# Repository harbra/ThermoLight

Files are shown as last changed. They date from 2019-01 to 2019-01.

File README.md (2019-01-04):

# ThermoLight - The IoT Thermometer & Display

## Project description
ThermoLight is a thermometer look-alike display that can show up to four values using NeoPixels & the ESP8266.

A more detailed description can be found on [hackster.io](https://www.hackster.io/har-bra/thermolight-the-iot-thermometer-display-c543e6).

## Repository contents
* C++ code that is running on the ESP8266, based on the Arduino core (in /code/esp8266)
* HTML/CSS/JS for webinterface, based on vue.js and Bulma (in /code/web)
* Schematic and PCB for the underlying electronics, created in KiCAD (in /pcb)
* Enclosure design, created in Fusion 360 (in /cad)

## Licenses
* All code is licensed with the [MIT license](https://opensource.org/licenses/MIT)
* Schematic, PCB and enclosure design are licensed with [CC-BY-SA-4.0](https://creativecommons.org/licenses/by-sa/4.0/)

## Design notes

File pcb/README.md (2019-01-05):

# ThermoLight - The IoT Thermometer & Display

## Project description
ThermoLight is a thermometer look-alike display that can show up to four values using NeoPixels & the ESP8266.

A more detailed description can be found on [hackster.io](https://www.hackster.io/har-bra/thermolight-the-iot-thermometer-display-c543e6).

## Folder contents
* Schematic and PCB for the underlying electronics, created in KiCAD
  * Some custom components are included in a custom KiCAD library in /mylibrary

## Licenses
* Schematic, PCB and enclosure design are licensed with [CC-BY-SA-4.0](https://creativecommons.org/licenses/by-sa/4.0/)

## BOM
_Note:_ CCS811 and iAQ-Core can detect the same information and are connected to the same I2C bus. So only one of them needs to be equipped.

| Ref | Qnty | Value | Part | Footprint | Comment |
| --- | ---- | ----- | ---- | --- | --- |
| C1, C2, C3, C5, C44 | 5 | 10u | device:C | Capacitors_SMD:C_1206_HandSoldering | Unpolarized capacitor |
| C4, C45 | 2 | 470u | device:CP | myfootprints:CP_Radial_D6.3mm_P2.50mm_lying | Polarised capacitor |
| C6, C7, C8, C9, C10, C11, C12, C13, C14, C15, C16, C17, C18, C19, C20, C21, C22, C23, C24, C25, C26, C27, C28, C29, C30, C31, C32, C33, C34, C35, C36, C37, C38, C39, C40, C41, C42, C43 | 38 | 0.1u | device:C | Capacitors_SMD:C_0603_HandSoldering | Unpolarized capacitor |
| J1 | 1 | 952-1951-ND | conn:Conn_01x03 | Pin_Headers:Pin_Header_Straight_1x03_Pitch2.54mm_SMD_Pin1Right | Generic connector, single row, 01x03 |
| J2 | 1 | USB_OTG | conn:USB_OTG | myfootprints:1051640001 | USB mini/micro connector |
| LED1, LED2, LED3, LED4, LED5, LED6, LED7, LED8, LED9, LED10, LED11, LED12, LED13, LED14, LED15, LED16, LED17, LED18, LED19, LED20, LED21, LED22, LED23, LED24, LED25, LED26, LED27, LED28, LED29, LED30, LED31, LED32, LED33, LED34, LED35, LED36, LED37, LED38 | 38 | WS2812B | Worldsemi:WS2812B | LEDs:LED_WS2812B-PLCC4 | RGB LED with integrated controller |
| PROG1, RST1 | 2 | TL3315NF160Q | switches:SW_Push | myfootprints:TL3315 | Push button switch, generic, two pins |
| R1, R2, R3, R4, R5, R6 | 6 | 10k | device:R | Resistors_SMD:R_0603_HandSoldering | Resistor |
| R7 | 1 | 470 | device:R | Resistors_SMD:R_0603_HandSoldering | Resistor |
| R8, R9, R10 | 3 | 4k7 | device:R | Resistors_SMD:R_0603_HandSoldering | Resistor |
| U1 | 1 | AP2112 | mylibrary:AP2112 | TO_SOT_Packages_SMD:SOT-23-5_HandSoldering | |
| U2 | 1 | ESP-12 | ESP8266:ESP-12 | myfootprints:ESP-12S_SMD | ESP8266 ESP-12 module, 16 pins, 2mm, PCB antenna |
| U3 | 1 | 74AHCT1G125 | mylibrary:74AHCT1G125 | TO_SOT_Packages_SMD:SOT-23-5_HandSoldering | |
| U4 | 1 | iAQ-Core | mylibrary:iAQ-Core | myfootprints:iAQ-Core | |
| U5 | 1 | SHT31-D | mylibrary:SHT31-D | myfootprints:DFN-8-2.5x2.5-0.5mm-handsolder | |
| U6 | 1 | CCS811 | mylibrary:CCS811 | myfootprints:LGA_CCS811 | |

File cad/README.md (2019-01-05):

# ThermoLight - The IoT Thermometer & Display

## Project description
ThermoLight is a thermometer look-alike display that can show up to four values using NeoPixels & the ESP8266.

A more detailed description can be found on [hackster.io](https://www.hackster.io/har-bra/thermolight-the-iot-thermometer-display-c543e6).

## Folder contents
* Enclosure design, created in Fusion 360
  * STL exports of the parts that need to be 3D printed
  * an SVG containing the outline for laser cuttig the diffusor. It is included in three variants that account for different laser kerfs so that the diffusor fits tightly in the main part of the enclosure

## Licenses
* Schematic, PCB and enclosure design are licensed with [CC-BY-SA-4.0](https://creativecommons.org/licenses/by-sa/4.0/)

## Hints
* It seems inserting the diffusor slightly warps/bends the main enclosure part. This can lead to a slight bulging of the back lid. I removed some material towards the top end of the lid where the M2 screw goes to reduce the warping of the back lid.

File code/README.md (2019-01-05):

# ThermoLight - The IoT Thermometer & Display

## Project description
ThermoLight is a thermometer look-alike display that can show up to four values using NeoPixels & the ESP8266.

A more detailed description can be found on [hackster.io](https://www.hackster.io/har-bra/thermolight-the-iot-thermometer-display-c543e6).

## Folder contents
* C++ code that is running on the ESP8266, based on the Arduino core (in /esp8266)
* HTML/CSS/JS for webinterface, based on vue.js and Bulma (in /web)

## Licenses
* All code is licensed with the [MIT license](https://opensource.org/licenses/MIT)

## Development workflow & some hints
All code was developed in PlatformIO. After pulling the repository from GitHub, the following steps are required to be able to start developing:
* Library dependencies for the Arduino-portion of the code should be pulled automatically by PlatformIO based on `/esp8266/platformio.ini`.
* Adjust `lib_dir` and `lib_extra_dirs` in `/esp8266/platformio.ini` according to your local file setup.
* Library and development dependencies for the webinterface need to be installed with `npm install` (this requires Node.js on your development machine). This pulls all required dependencies as specified in `/web/package.json`.
* If changes on the webinterface have been done, use `npm run build` to package the files. The output is generated in `/web/dist/`. Copy the contents of this folder to `/esp8266/data/html/dist`.
  _CAUTION:_ In order for iOS to be able to load the webinterface, only the gzipped version of `build.js` and `style.css` should be copied to `/esp8266/data/html/dist`.
* For uploading to the ThermoLight, two approaches exist:
  * *wired:* connect a USB-to-serial-converter to the respective pins on the PCB. The respective pins are towards the top end of the PCB, below the ESP8266 and are labelled GND, TX and RX.
    Please note that `upload_port` needs to be commented out.
  * *wireless:* Make sure the ESP8266 and your development machine are conncted to the same wireless network.
    Please note that `upoad_port` in `/esp8266/platformio.ini` needs to be set to the ESP8266's IP address or host name (default: thermolight.local).
* To upload changes in the file contents in `/esp8266/data` to the ESP8266's SPIFFS, use the PlatformIO "other target" `PIO Upload SPIFFS image`
* To upload changes of the general ESP8266 code, use the standard build target `PIO build` (doesn't overwrite SPIFFS file system)
* To save time during development and avoid repeated uploads to the SPIFFS memory (because they take time), connect the ESP8266 to the same Wifi network as your development machine and  uncomment the `baseURL` parameter in `/web/src/plugins/axios.js`. Set the `baseURL` to the ESP's IP address or host name (default: thermolight.local). Then use `npm run dev` to fire up a local development server. All API-calls to the ESP should still be answered by the ESP, however the webinterface will be served locally.

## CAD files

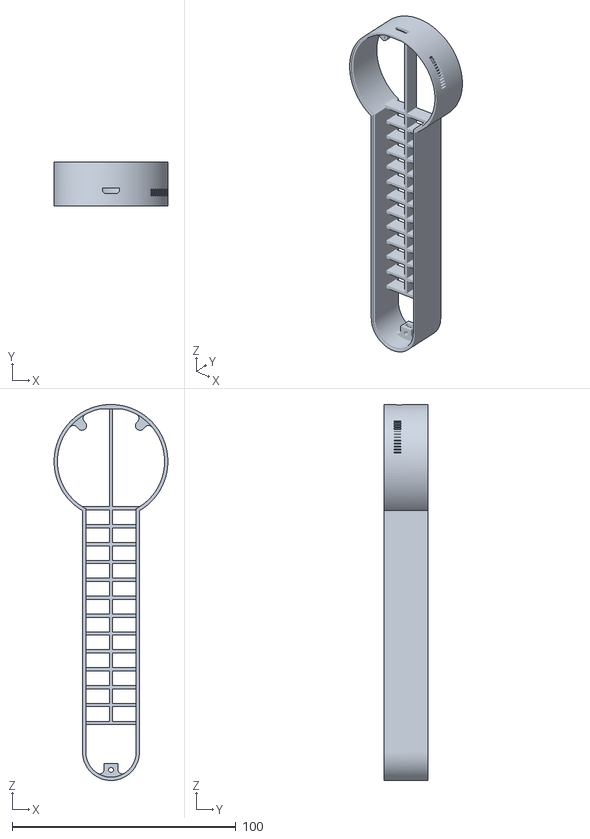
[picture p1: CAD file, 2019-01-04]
cad/stl_export/Enclosure.stl
50.9 x 19.6 x 168.2

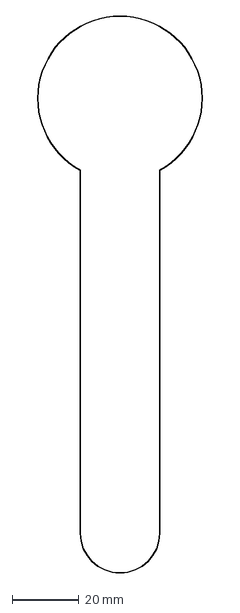
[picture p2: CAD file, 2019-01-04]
cad/svg_export/diffusor_02.dxf
53.1 x 166.4 mm

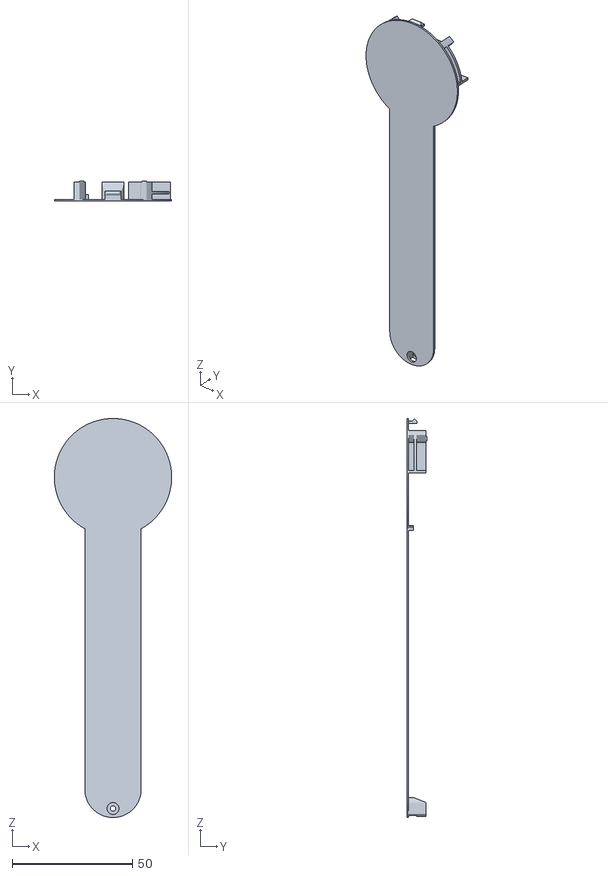
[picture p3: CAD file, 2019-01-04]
cad/stl_export/Lid.stl
48.9 x 8.50 x 166.2

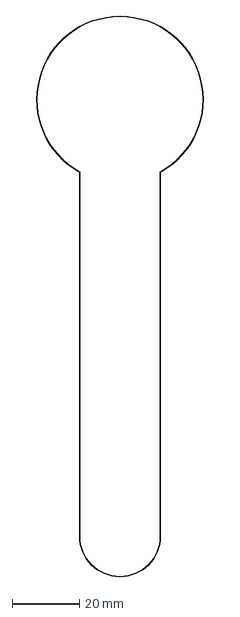
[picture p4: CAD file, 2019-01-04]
cad/svg_export/diffusor_001.dxf
53.6 x 166.8 mm

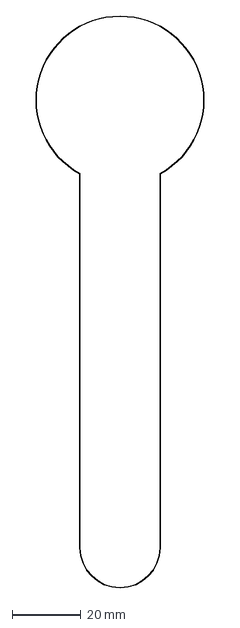
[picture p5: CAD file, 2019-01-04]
cad/svg_export/diffusor_04.dxf
52.7 x 166.0 mm

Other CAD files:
cad/ThermoLight v39.f3d

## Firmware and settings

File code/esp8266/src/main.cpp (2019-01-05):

/*
License
=======

MIT License

Copyright (c) 2019 Harald Braun

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
THE SOFTWARE IS PROVIDED "AS IS", WITHOUT WARRANTY OF ANY KIND, EXPRESS OR
IMPLIED, INCLUDING BUT NOT LIMITED TO THE WARRANTIES OF MERCHANTABILITY,
FITNESS FOR A PARTICULAR PURPOSE AND NONINFRINGEMENT. IN NO EVENT SHALL THE
AUTHORS OR COPYRIGHT HOLDERS BE LIABLE FOR ANY CLAIM, DAMAGES OR OTHER
LIABILITY, WHETHER IN AN ACTION OF CONTRACT, TORT OR OTHERWISE, ARISING FROM,
OUT OF OR IN CONNECTION WITH THE SOFTWARE OR THE USE OR OTHER DEALINGS IN THE
SOFTWARE.
*/

#include <stdlib.h>
#if ARDUINO >= 100
#include <Arduino.h>
#else
#include <WProgram.h>
#include <wiring.h>
#endif

#include "FS.h"
#include <time.h>

#include <ThermoLight.h>
#include <AsyncHTTPRequest.hpp>

#include <Logger.h>

ThermoLight thermoLight;

void setup() {
  // put your setup code here, to run once:
  Serial.begin(115200);
  Serial.setDebugOutput(true);

  myLogger.addToLog("Starting...");

  thermoLight.setup();
}

void loop() {
    // put your main code here, to run repeatedly:
    thermoLight.handle();
}

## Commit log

2019-01-04 Uploaded CAD data and started work on the code directory.
    [Enclosure.stl, Lid.stl, ThermoLight v39.f3d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]
2019-01-05 Prepared PCB data for GitHub.
    [AP2112.sch, esp-12s.sch, thermolight.kicad_pcb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]
2019-01-05 Fixed PCB README.md.
